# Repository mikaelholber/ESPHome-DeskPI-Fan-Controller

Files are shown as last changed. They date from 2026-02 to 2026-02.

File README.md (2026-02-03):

# ESPHome-Fan-Controller
The ESPHome-Fan-Controller was built gor a very specific purpose. To limit the noise while keeping the DeskPi rack cooled to a set temperature. 

My minilab is located in the bedroom and tucked away in such a way that I need good airflow at the lowest possible noise. To achive this i decided to use ESPHome to control a few 5V fans which can be mounted in the vented blanks available.

BoardDesign
3D-view




The schematics and ESPHome configuration is derived from https://github.com/patrickcollins12/esphome-fan-controller and the only original work is the PCB layout to fit the specific envelope in the vented blank. 

### This repository contains
* The KiCad schematics
* The KiCad PCB layout
* The KiCad Project file
* BOM and CPL for production at JLCPCB
* The ESPHome yaml files for manual control via either ESPHome webserver interface or Home Assistant
* The automation for Home Assistant to change fan speed based on Server CPU temp using Glances integration

### Board features
* The controller is based on the ESP32-S3-MINI-1-N4R2
* The controller fits neatly in a 40mm fan slot (32x32mm M3 screw holes) and features a vertical USB-C connector for programming and power. 

# Prepare the yaml
Change the friendly name to your liking and set the wifi-ssid and password.

# Programming
1. Install ESPHome and build (Install) the yaml file.
2. Choose plug into computer option.
3. Plug the controller into your computer and hold down the boot button WHILE selecting the Jtag in the pop-up window.
4. Wait for the firmware to install

If ESPhome returns an error before installing the firmware, try to hold the boot button WHILE plugging it into the computer. I'm not sure what order is required - Maybe see the documentation.

Check that the installation works by going to the name you choose .local
esphomelocal

# Home Assistant
Install the ESPHome integration in Home Assistant.
Add a device and point to the local address of the Fan controller OR the IP-address.

I have 4 automations controlling the fans:
1. Setting the base speed at 7am to 60% (it gets warmer in the day)
2. Setting the base speed at 7.30pm to 30% (lower the noise in the night)
3. Set HIGH speed if the temperature goes above a certain temperature (See High-speed.yaml)
4. Set LOW speed if the temperature goes down again (See Low-speed.yaml)

# Purchasing boards
You can order boards in EU from me on Tindie: https://www.tindie.com/products/holber/minilab-esp-home-fan-controller-40x40mm

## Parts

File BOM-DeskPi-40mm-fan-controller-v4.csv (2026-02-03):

Comment | Designator | Footprint | LCSC | Quantity
0.1nF | C11,C7,C8,C9 | C_0402_1005Metric | C1546 | 4
1.5Amp | F1 | Fuse_0603_1608Metric | C126814 | 1
10000R | R10,R12,R14,R3,R7,R9 | R_0402_1005Metric | C25744 | 6
1000R | R6 | R_0402_1005Metric | C11702 | 1
100nF | C1,C10,C5 | C_0402_1005Metric | C1525 | 3
1uF | C2,C3,C4,C6 | C_0402_1005Metric | C52923 | 4
3300R | R11,R13,R15,R8 | R_0402_1005Metric | C25890 | 4
4700R | R4,R5 | R_0402_1005Metric | C25900 | 2
5100R | R1,R2 | R_0402_1005Metric | C25905 | 2
705430038 | Fan1,Fan2,Fan3,Fan4 | CONN-TH_47053-1000 | C240840 | 4
BME280 | U3 | Bosch_LGA-8_2.5x2.5mm_P0.65mm_ClockwisePinNumbering | C92489 | 1
ESP32-S3-MINI-1 | U1 | ESP32-S3-MINI-1 | C3013941 | 1
GT-USB-7052 | USB1 | USB-C-SMD_GT-USB-7052_1 | C963223 | 1
LED | D1 | LED_0603_1608Metric | C2286 | 1
TLV76733DGNR | U2 | MSOP-8_L3.0-W3.0-P0.65-LS4.9-BL-EP-1 | C2873382 | 1
TS-1088-AR02016 | BOOT1,RESET1 | SW-SMD_L3.9-W3.0-P4.45 | C720477 | 2
USBLC6-2SC6_C2687116 | D2 | SOT-23-6_L2.9-W1.6-P0.95-LS2.8-BL | C2687116 | 1

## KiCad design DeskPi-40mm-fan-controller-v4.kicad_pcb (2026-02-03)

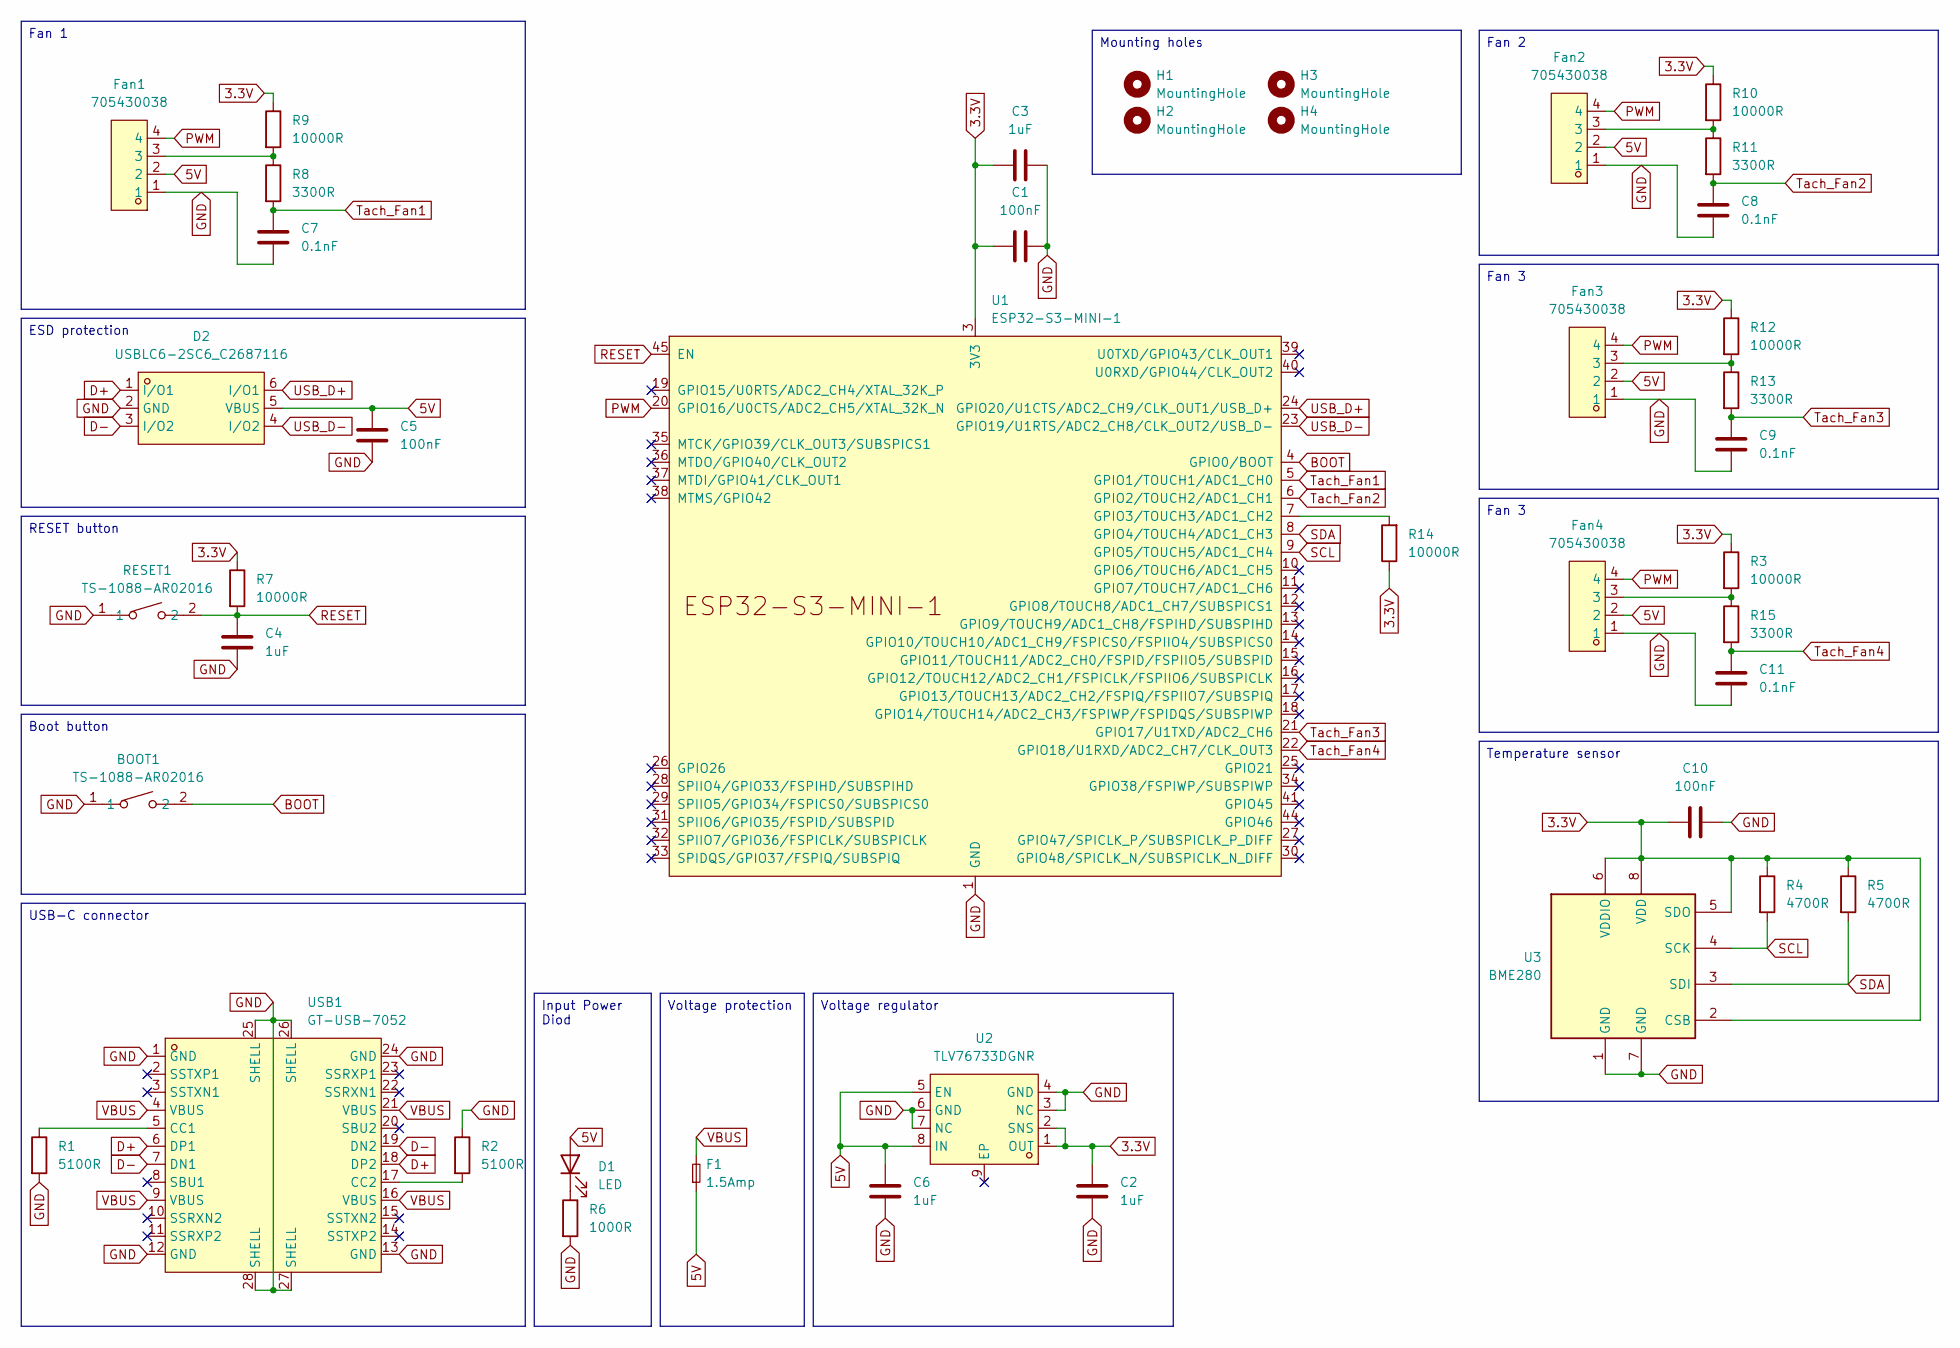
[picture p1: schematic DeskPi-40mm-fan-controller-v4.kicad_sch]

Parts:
BOOT1: TS-1088-AR02016; SW-SMD_L3.9-W3.0-P4.45; LCSC Part C720477
C1, C5, C10: 100nF; C_0402_1005Metric
C2, C3, C4, C6: 1uF; C_0402_1005Metric
C7, C8, C9, C11: 0.1nF; C_0402_1005Metric
D1: LED; LED_0603_1608Metric
D2: USBLC6-2SC6_C2687116; SOT-23-6_L2.9-W1.6-P0.95-LS2.8-BL; LCSC Part C2687116
F1: 1.5Amp; Fuse_0603_1608Metric
Fan1, Fan2, Fan3, Fan4: 705430038; CONN-TH_47053-1000; LCSC Part C240840
H1, H2, H3, H4: MountingHole; MountingHole_3.2mm_M3_DIN965_Pad
R1, R2: 5100R; R_0402_1005Metric
R3, R7, R9, R10, R12, R14: 10000R; R_0402_1005Metric
R4, R5: 4700R; R_0402_1005Metric
R6: 1000R; R_0402_1005Metric
R8, R11, R13, R15: 3300R; R_0402_1005Metric
RESET1: TS-1088-AR02016; SW-SMD_L3.9-W3.0-P4.45; LCSC Part C720477
U1: ESP32-S3-MINI-1
U2: TLV76733DGNR; MSOP-8_L3.0-W3.0-P0.65-LS4.9-BL-EP-1; LCSC Part C2873382
U3: BME280; Bosch_LGA-8_2.5x2.5mm_P0.65mm_ClockwisePinNumbering
USB1: GT-USB-7052; USB-C-SMD_GT-USB-7052_1; LCSC Part C963223

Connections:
3.3V: C1.1, C2.2, C3.2, C10.2, R3.1, R4.1, R5.1, R7.1, R9.1, R10.1, R12.1, R14.1, U1.3 (3V3), U2.1 (OUT), U2.2 (SNS), U3.2 (CSB), U3.5 (SDO), U3.6 (VDDIO), U3.8 (VDD)
5V: C5.2, C6.1, D1.2 (A), D2.5 (VBUS), F1.1, Fan1.2, Fan2.2, Fan3.2, Fan4.2, U2.5 (EN), U2.8 (IN)
BOOT: BOOT1.2, U1.4 (GPIO0/BOOT)
D+: D2.1 (I/O1), USB1.6 (DP1), USB1.18 (DP2)
D-: D2.3 (I/O2), USB1.7 (DN1), USB1.19 (DN2)
GND: BOOT1.1, C1.2, C2.1, C3.1, C4.1, C5.1, C6.2, C7.1, C8.1, C9.1, C10.1, C11.1, D2.2 (GND), Fan1.1, Fan2.1, Fan3.1, Fan4.1, R1.2, R2.1, R6.2, RESET1.1, U1.1 (GND), U1.2 (GND), U1.42 (GND), U1.43 (GND), U1.46 (GND), U1.47 (GND), U1.48 (GND), U1.49 (GND), U1.50 (GND), U1.51 (GND), U1.52 (GND), U1.53 (GND), U1.54 (GND), U1.55 (GND), U1.56 (GND), U1.57 (GND), U1.58 (GND), U1.59 (GND), U1.60 (GND), U1.61 (GND), U1.62 (GND), U1.63 (GND), U1.64 (GND), U1.65 (GND), U2.3 (NC), U2.4 (GND), U2.6 (GND), U2.7 (NC), U3.1 (GND), U3.7 (GND), USB1.1 (GND), USB1.12 (GND), USB1.13 (GND), USB1.24 (GND), USB1.25 (SHELL), USB1.26 (SHELL), USB1.27 (SHELL), USB1.28 (SHELL)
unnamed: D1.1 (K), R6.1
unnamed: Fan1.3, R8.1, R9.2
unnamed: Fan2.3, R10.2, R11.1
unnamed: Fan3.3, R12.2, R13.1
unnamed: Fan4.3, R3.2, R15.1
unnamed: R14.2, U1.7 (GPIO3/TOUCH3/ADC1_CH2)
unnamed: R1.1, USB1.5 (CC1)
unnamed: R2.2, USB1.17 (CC2)
PWM: Fan1.4, Fan2.4, Fan3.4, Fan4.4, U1.20 (GPIO16/U0CTS/ADC2_CH5/XTAL_32K_N)
RESET: C4.2, R7.2, RESET1.2, U1.45 (EN)
SCL: R4.2, U1.9 (GPIO5/TOUCH5/ADC1_CH4), U3.4 (SCK)
SDA: R5.2, U1.8 (GPIO4/TOUCH4/ADC1_CH3), U3.3 (SDI)
Tach_Fan1: C7.2, R8.2, U1.5 (GPIO1/TOUCH1/ADC1_CH0)
Tach_Fan2: C8.2, R11.2, U1.6 (GPIO2/TOUCH2/ADC1_CH1)
Tach_Fan3: C9.2, R13.2, U1.21 (GPIO17/U1TXD/ADC2_CH6)
Tach_Fan4: C11.2, R15.2, U1.22 (GPIO18/U1RXD/ADC2_CH7/CLK_OUT3)
USB_D+: D2.6 (I/O1), U1.24 (GPIO20/U1CTS/ADC2_CH9/CLK_OUT1/USB_D+)
USB_D-: D2.4 (I/O2), U1.23 (GPIO19/U1RTS/ADC2_CH8/CLK_OUT2/USB_D-)
VBUS: F1.2, USB1.4 (VBUS), USB1.9 (VBUS), USB1.16 (VBUS), USB1.21 (VBUS)

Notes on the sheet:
Fan 3
RESET button
Input Power Diod
ESD protection
Fan 2
Temperature sensor
Boot button
Voltage protection
USB-C connector
Fan 1
Mounting holes
Voltage regulator

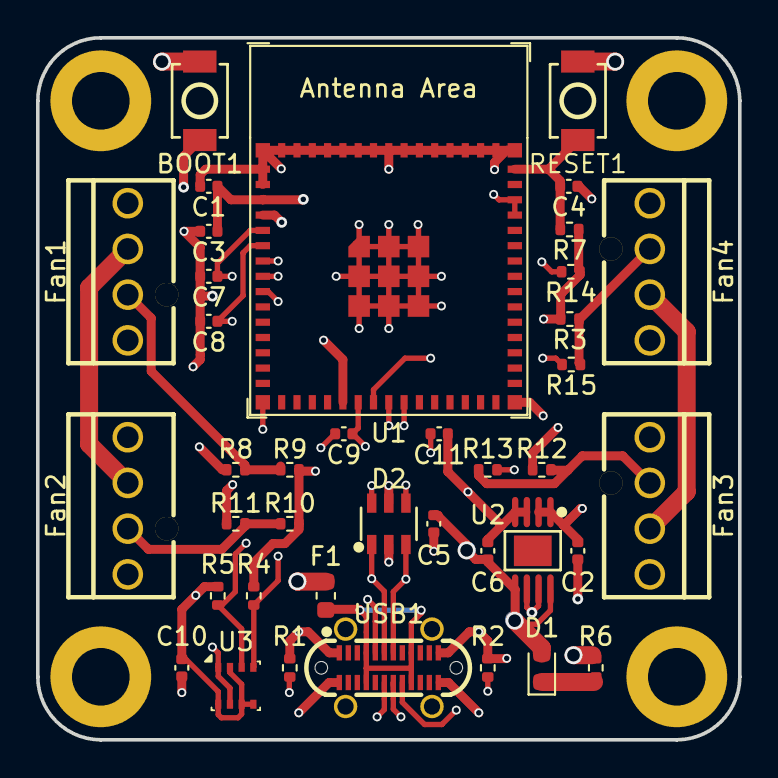
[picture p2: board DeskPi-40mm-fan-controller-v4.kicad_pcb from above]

Board: 4 copper layers, 39.0 x 39.0 mm, 43 parts (0 on the bottom side), 25 nets.

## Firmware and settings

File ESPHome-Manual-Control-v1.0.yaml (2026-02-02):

substitutions:
  friendly_name: Homelab Fan

esphome:
  name: homelab
  comment: ESP32 Temperature and Fan Controller

# Throttle writing parameters to the internal flash memory to reduce ESP memory wear / degradation
preferences:
  flash_write_interval: 15min

# Version of the board
esp32:
  variant: esp32s3

# Enable logging
logger:
  level: DEBUG

# Enable Home Assistant API
api:
  port: 6053
  batch_delay: 50ms  # Reduce latency for real-time applications
  listen_backlog: 2  # Allow 2 pending connections in queue
  max_connections: 6  # Allow up to 6 simultaneous connections
  max_send_queue: 10  # Maximum queued messages per connection before disconnect

ota:
  - platform: esphome
  
# WiFi connection to network
wifi:
  ssid: YOUR_SSID
  password: YOUR_CODE

  # Enable fallback hotspot (captive portal) in case wifi connection fails
  ap:
    ssid: "HomeLab-Fallback-Temp"
    password: "TESTPASS"

captive_portal:
text_sensor:

  # Send IP Address
  - platform: wifi_info
    ip_address:
      name: $friendly_name IP Address

  # Send Uptime in raw seconds
  - platform: template
    name: $friendly_name Uptime
    id: uptime_human
    icon: mdi:clock-start

# BME280 Temperature sensor specific configurations
i2c:
  sda: GPIO04
  scl: GPIO05
  scan: true
  id: bus_a

# BME280 Temperature sensor
sensor:
  - platform: bme280_i2c
    temperature:
      name: $friendly_name Temperature
      id: homelab_fan_temperature
      oversampling: 16x
    pressure:
      name: $friendly_name Pressure
    humidity:
      name: $friendly_name Humidity
    address: 0x77
    update_interval: 30s

####################
# Fan RPM counters #
####################
  - platform: pulse_counter
    pin: 
      number: GPIO1   # Connect to any input PIN on the ESP
      mode: INPUT_PULLUP
    unit_of_measurement: 'RPM'
    id: fan_1_speed
    name: Fan Speed 1
    accuracy_decimals: 0
    filters:
      - multiply: 0.5  # Depending on how many pulses the fan sends per round - should be 0.5 or 1 - try...

  - platform: pulse_counter
    pin: 
      number: GPIO2   # Connect to any input PIN on the ESP
      mode: INPUT_PULLUP
    unit_of_measurement: 'RPM'
    id: fan_2_speed
    name: Fan Speed 2
    accuracy_decimals: 0
    filters:
      - multiply: 0.5  # Depending on how many pulses the fan sends per round - should be 0.5 or 1 - try...

  - platform: pulse_counter
    pin: 
      number: GPIO17   # Connect to any input PIN on the ESP
      mode: INPUT_PULLUP
    unit_of_measurement: 'RPM'
    id: fan_3_speed
    name: Fan Speed 3
    accuracy_decimals: 0
    filters:
      - multiply: 0.5  # Depending on how many pulses the fan sends per round - should be 0.5 or 1 - try...

  - platform: template
    name: "Fan Speed (PWM Voltage)"
    unit_of_measurement: "%"
    id: fan_speed_pwm_voltage

###################################
# Report uptime to Home Assistant #
###################################
  - platform: uptime
    name: $friendly_name Uptime
    id: uptime_sensor
    update_interval: 60s
    on_raw_value:
      then:
        - text_sensor.template.publish:
            id: uptime_human
            # Custom C++ code to generate the result
            state: !lambda |-
              int seconds = round(id(uptime_sensor).raw_state);
              int days = seconds / (24 * 3600);
              seconds = seconds % (24 * 3600);
              int hours = seconds / 3600;
              seconds = seconds % 3600;
              int minutes = seconds /  60;
              seconds = seconds % 60;
              return (
                (days ? to_string(days) + "d " : "") +
                (hours ? to_string(hours) + "h " : "") +
                (minutes ? to_string(minutes) + "m " : "") +
                (to_string(seconds) + "s")
              ).c_str();

########################
# Fan speed controller #
########################
output:
  # Wire this pin (16) into the PWM pin of your 5v fan
  # ledc is the name of the pwm output system on an esp32
  - platform: ledc
    id: fan_speed
    pin: GPIO16

    # 25KHz is standard PC fan frequency, minimises buzzing
    frequency: "25000 Hz" 

    # my fans stop working below 13% powerful.
    # also they're  powerful and loud, cap their max speed to 80%
    min_power: 13%
    max_power: 80%

    # At 0, actually turn it off, otherwise the power keeps going.
    zero_means_zero: true

  - platform: template
    id: proxy_output
    type: float
    write_action:
      lambda: |-
        float write_val = 
          (id(manual_fan_control).state) ?
            id(manual_fan_control).speed / 100.0 : state*1.0;
        id(fan_speed).set_level(write_val);
        id(fan_speed_pwm_voltage).publish_state(write_val*100.0);

# If you turn this on, you can manually set the fan speed.
# The PID will be ignored. This is done via the proxy_output
fan:
  - platform: speed
    id: manual_fan_control
    output: proxy_output
    name: "Manual Fan Speed"
    restore_mode: ALWAYS_ON
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

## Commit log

2025-12-11 KiCad files for v1.0
    KiCad 9.0 files for DeskPi 40mm Dual Fan Controller board v1.0
    [DeskPi 40mm Dual Fan Controller.kicad_pcb, DeskPi 40mm Dual Fan Controller.kicad_sch]
2026-02-03 Change to fully integrated chip
    [BOM-DeskPi-40mm-fan-controller-v4.csv, DeskPi 40mm Dual Fan Controller.kicad_pcb, DeskPi 40mm Dual Fan Controller.kicad_sch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]
